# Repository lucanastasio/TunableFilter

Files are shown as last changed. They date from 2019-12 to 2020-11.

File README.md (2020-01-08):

# Tunable Filter with varactors
## Idea (our goal)
The idea of this project is the design of a tunable filter with variable resonance frequency. Achieving this would be possible using varactors. The varactors are used in place of the capacitors in resonators thanks to their abrupt juction that results in an high variation in capacitance with respect to the voltage applied across their terminals. So the varactor is the tuning component in this project. The use of this component will be explained in the following notes.

## Design specifications
The (approximate) design specifications used in the design of this filter are the following:

- ***Type of Filter:*** band-pass
- ***Type of Response:*** Chebyshev (equi-ripple)
- ***Order of the filter:*** Third Order
- ***Resonant frequency:***  (adjustable)
- ***Bandwitdh:***  (adjustable)
- ***Ports Impedances:*** 
- ***Ripple Level:***  (adjustable)

## Design of the ideal Filter
The project started with the design of the ideal pass-band filter in order to verify that all the specifications can be satisfied. For the design, the method used was ***Insertion Loss Method*** taking the low-pass Filter prototype and changing the series and shunt components in order to have a pass-band response. Below is the schematic of the ideal pass-band filter:

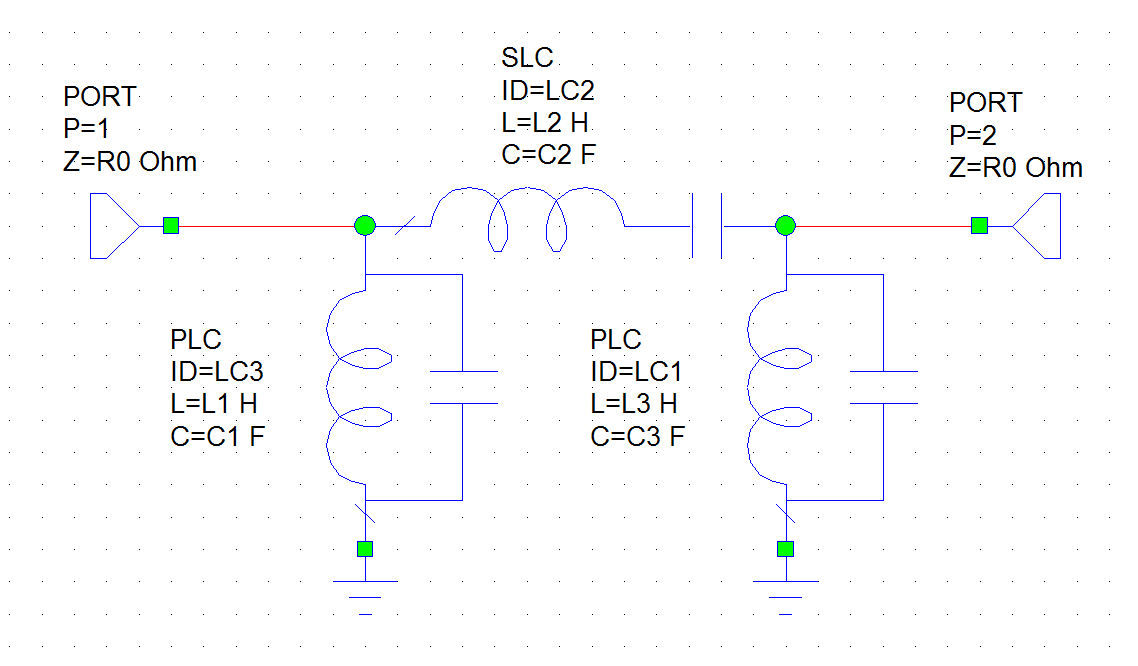
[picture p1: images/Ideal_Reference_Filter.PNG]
Ideal pass-band filter


Formulas used in the first design stage:

- 
- 
- 
- 
- 
- 

where:

-  : band-pass prototype filter coefficients, calculate as a third order Chebyshev filter [unitless]
-  : fractional bandwidth [%]
-  : angular frequency [rad/s]

The above formulas take into account impedance scaling and frequency scaling since the low-pass prototype uses an angular frequency at the resonant frequency of  and a source impedance of .
The resonant frequency (hence the fractional bandwidth) is not specified at this point of the design, instead it's left as a parameter. Then simulation environment's tuner tool (AWR) allows sweeping the parameter in its range.

In order to set an arbitrary inductor value for the resonators, impedance inverters were used with a proper value of ***K*** (inverter parameter). The resonator inductor value is called  in the schematic and its value is not yet determined, it's again a tunable value in order to obtain the best value which can be found as an off-the-shelf component. Thus, in the schematic of the pass-band filter, 4 impedance inverters were added, as shown in the following image:

Ideal pass-band filter with inverters

The resonator capacitor value is set by the equation:



The above equation gives the proper value of  for the desired resonat frequency.

Following are the formulas used to compute ***K*** parameters for each inverter:

- K for the impedence inverter at the source: 
- K for the second impedence inverter: 
- K for the third impedence inverter: 
- K for the impedence inverter at the load: 

where  is the source impedance,  is the bandwidth expressed in terms of angular frequency,  is the desired resonator inductance, and  are the band-pass filter prototype coefficients.

At this point impedance inverters are implemented as quarter-wave long transmission lines. The range of working frequencies spans from 0 to 1 GHz, so the physical length of the transmission lines results in an unfeasible dimension for a printed circuit board. To minimize board dimensions, the most reasonable choice is to implement the filter with lumped elements only, so an equivalent circuit for impedance inverters is required. For the 2 impedance inverters in the middle of the filter, the equivalent circuit is a T circuit composed of three capacitors where the shunt capacitor has a positive capacitance while the serires capacitors have a negative capacitance. Capacitors with negative capacitance are not physically possible but the use of this component is useful in the theoric design phase. Negative capacitors will be "absorbed" by the series with resonator capacitors, but only if the negative capacitors have a capacitance (in magnitude) greater than the resonator's one.
However, negative capacitances of impedance inverters at source and load ports are not "absorbed". To solve this problem another equivalent circuit is required for those two special cases, it consists of a shunt positive capacitor and only one series negative capacitor.
The schematic where all the impedance inverters are replaced with their respective equivalent circuits is shown in the figure:

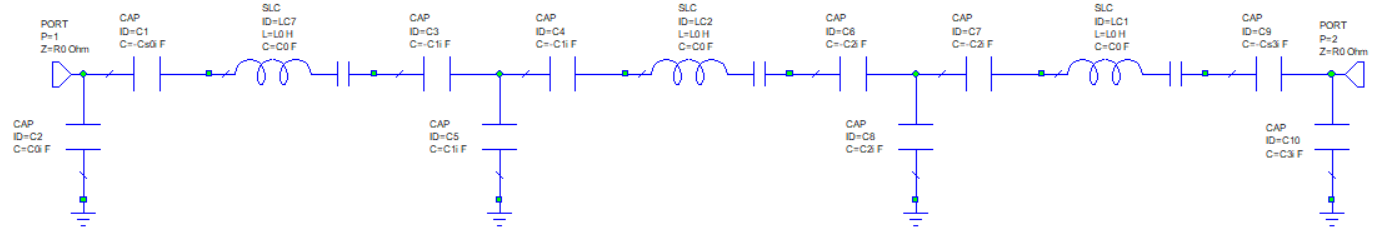
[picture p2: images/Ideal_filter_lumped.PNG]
Ideal pass-band filter with equivalent circuits of inverter Ideal pass-band filter with equivalent circuits of inverters


The formulas used to calculate capacitor values are:

- Impedance inverter at the source: 
	- shunt capacitor 
	- series capacitor 
- Second impedance inverter:
	- all capacitors have the same value 
- Third impedance inverter:
	- all capacitors have the same value 
- Impedance inverter at the load: 
	- shunt capacitor 
	- series capacitor 

Thanks to the symmetry of the circuit one has that  and .

As a last step of the design of the ideal pass-band filter, negative capacitors are "absorbed" by positive capacitors of the resonators. The final circuit is the following:

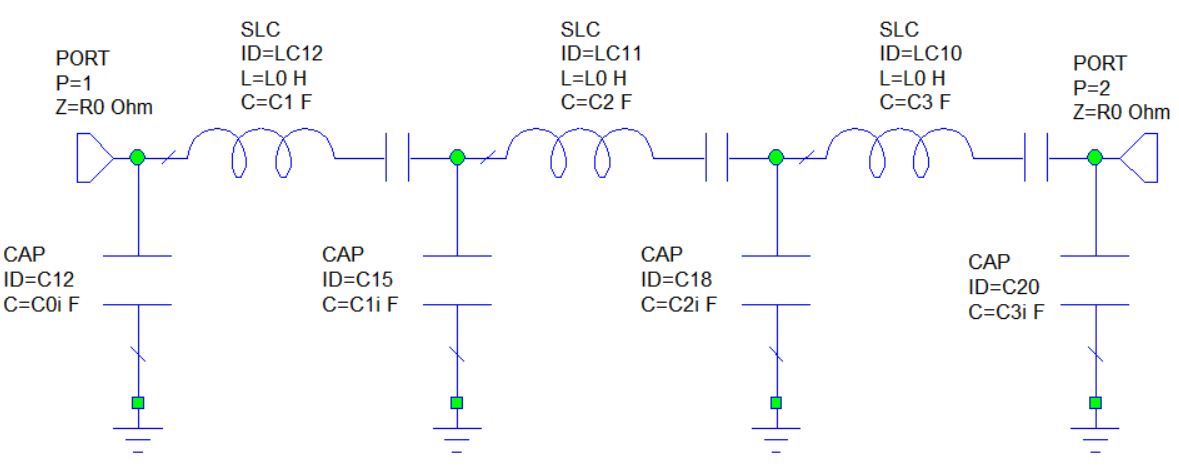
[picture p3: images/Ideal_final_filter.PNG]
Final design of the ideal pass-band filter


Capacitances are calculated using the well-known formula for series capacitance, thus:

- 
- 
- 

As per the circuit symmetry, .
It may be noted that the plus sign in front of  and  is due to the fact that the minus sign is inclued in their formulas.

Frequency response at the test resonant frequency of 1GHz of the final design of the ideal filter (without varactor) is shown below for ripple levels of 0.5 dB and 3dB respectively:

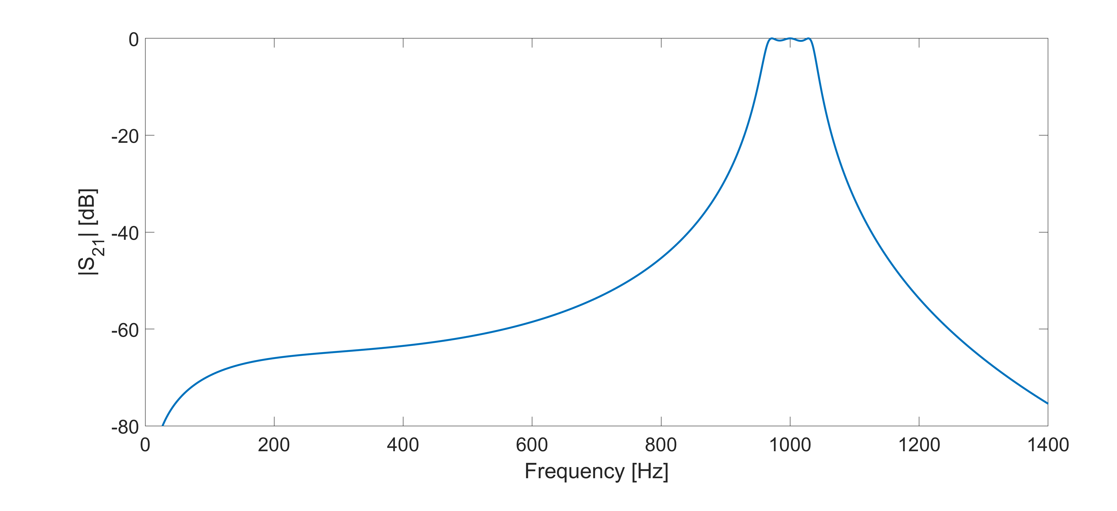
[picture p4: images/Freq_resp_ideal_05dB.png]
Frequency response 0.5dB Frequency response of the ideal filter for 0.5dB ripple level


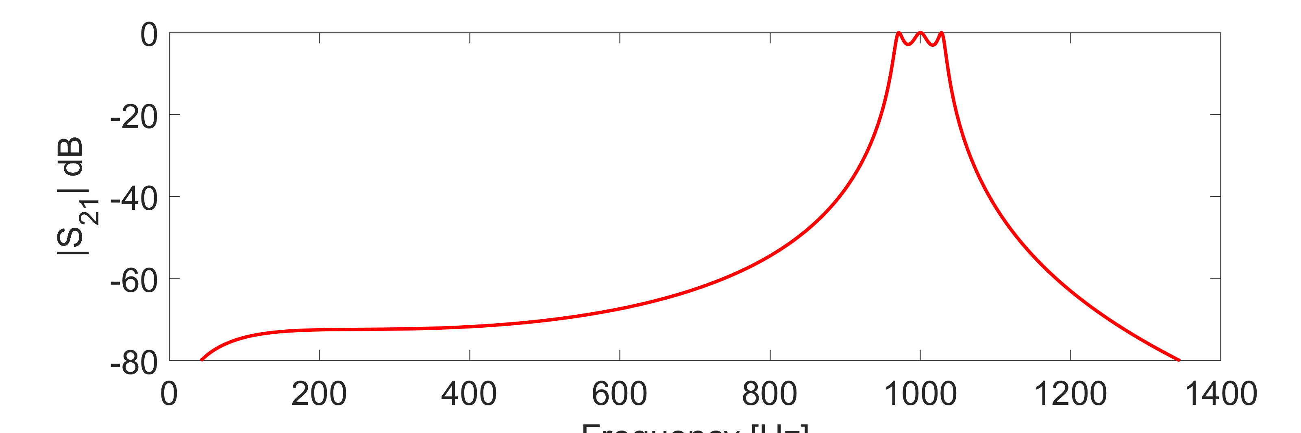
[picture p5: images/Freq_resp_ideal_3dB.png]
Frequency response 3dB Frequency response of the ideal filter for 3dB ripple level


## Adding tunable element: the varactor

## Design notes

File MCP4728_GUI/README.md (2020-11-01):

## Usage

### Driver
Only tested on Arch Linux, actual configuration may vary on your system, don't follow our isntructions blindly, do it at your own risk.

A CP2112 USB to i2c adapter has been used, but newer kernels don't load `i2c-dev` module on boot, load it on purpose with `sudo modprobe i2c-dev` and then, for your convenience, `echo '12c-dev' | sudo tee /etc/modules-load.d/i2c-dev.conf` to load it on boot.

Add an i2c group with `sudo groupadd i2c` to use it as normal user, add yourself to that group with `sudo usermod -a $USER -G i2c` and make the group effective in the current shell with `newgrp i2c` to avoid having to log out and back in.

Create an udev rule to ensure permission to use the adapter with `echo 'KERNEL=="i2c-[0-9]*", GROUP="i2c", MODE="0660"' | sudo tee /etc/udev/rules.d/99-i2c-dev.rules` and plug the adapter, finally.

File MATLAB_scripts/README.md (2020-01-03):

Extraction of the function that gives the biasing voltage to be applied to the diode in order to obtain the desired capacitance:

* Import the datasheet in Engauge Digitizer
* Extract the curve points and export the data
* Import the data in MATLAB and andjust the units if necessary
* Open the curve fitting tool and use C data for X axis and V data for Y axis
* Select the appropriate fitting type and adjust the fit
* To verify that the fit corresponds to the graph in the datasheet, first export the fit to the MATLAB workspace as "fit", then:
~~~matlab
plot(fit)
% comment/don't use the following if the voltage isn't in log scale
set(gca, 'YScale', 'log')
% swap X and Y axes
view([90 -90])
~~~

For example, the resulting function for BB202 extracted from the datasheet graph was:
~~~matlab
V(Cx) = (p1*Cx^3 + p2*Cx^2 + p3*Cx + p4) / (Cx^4 + q1*Cx^3 + q2*Cx^2 + q3*Cx + q4)
% with:
Cx = (C - 2.006e-11) / 9.593e-12
p1 = -1312
p2 = -4819
p3 = 2384
p4 = 1.172e+04
q1 = 974.2
q2 = 5311
q3 = 1.313e+04
q4 = 1.153e+04
~~~

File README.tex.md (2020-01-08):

# Tunable Filter with varactors
## Idea (our goal)
The idea of this project is the design of a tunable filter with variable resonance frequency. Achieving this would be possible using varactors. The varactors are used in place of the capacitors in resonators thanks to their abrupt juction that results in an high variation in capacitance with respect to the voltage applied across their terminals. So the varactor is the tuning component in this project. The use of this component will be explained in the following notes.

## Design specifications
The (approximate) design specifications used in the design of this filter are the following:

- ***Type of Filter:*** band-pass
- ***Type of Response:*** Chebyshev (equi-ripple)
- ***Order of the filter:*** Third Order
- ***Resonant frequency:*** $500MHz--1GHz$ (adjustable)
- ***Bandwitdh:*** $1\%-10\%$ (adjustable)
- ***Ports Impedances:*** $R_0=50\Omega$
- ***Ripple Level:*** $Ar=0.5\,dB$ (adjustable)

## Design of the ideal Filter
The project started with the design of the ideal pass-band filter in order to verify that all the specifications can be satisfied. For the design, the method used was ***Insertion Loss Method*** taking the low-pass Filter prototype and changing the series and shunt components in order to have a pass-band response. Below is the schematic of the ideal pass-band filter:

Ideal pass-band filter

Formulas used in the first design stage:

- $L1 = \frac{\Delta R_0}{g_1 \omega_0} H$
- $C1 = \frac{g_1}{\Delta R_0 \omega_0} F$
- $L2 = \frac{g_2 R_0}{\Delta \omega_0} H$
- $C2 = \frac{\Delta}{R_0 g_2 \omega_0} F$
- $L3 = \frac{\Delta R_0}{g_3 \omega_0} H$
- $C3 = \frac{g_3}{\Delta R_0 \omega_0} F$

where:

- $g_m$ : band-pass prototype filter coefficients, calculate as a third order Chebyshev filter [unitless]
- $\Delta$ : fractional bandwidth [%]
- $\omega_0$ : angular frequency [rad/s]

The above formulas take into account impedance scaling and frequency scaling since the low-pass prototype uses an angular frequency at the resonant frequency of $1 rad/sec$ and a source impedance of $R_0=1 \Omega$.
The resonant frequency (hence the fractional bandwidth) is not specified at this point of the design, instead it's left as a parameter. Then simulation environment's tuner tool (AWR) allows sweeping the parameter in its range.

In order to set an arbitrary inductor value for the resonators, impedance inverters were used with a proper value of ***K*** (inverter parameter). The resonator inductor value is called $L_0$ in the schematic and its value is not yet determined, it's again a tunable value in order to obtain the best value which can be found as an off-the-shelf component. Thus, in the schematic of the pass-band filter, 4 impedance inverters were added, as shown in the following image:

Ideal pass-band filter with inverters

The resonator capacitor value is set by the equation:

\begin{equation}
C_0 = \frac{1}{L_0 \omega_0^2}
\end{equation}

The above equation gives the proper value of $C_0$ for the desired resonat frequency.

Following are the formulas used to compute ***K*** parameters for each inverter:

- K for the impedence inverter at the source: $K_0=\sqrt{\frac{R_0 L_0BW}{g_0 g_1}}$
- K for the second impedence inverter: $K_1=\frac{BW L_0}{g_1 g_2}$
- K for the third impedence inverter: $K_2=\frac{BW L_0}{g_2 g_3}$
- K for the impedence inverter at the load: $K_3=\sqrt{\frac{R_0 L_0 BW}{g_3 g_4}}$

where $R_0$ is the source impedance, $BW$ is the bandwidth expressed in terms of angular frequency, $L_0$ is the desired resonator inductance, and $g_i$ are the band-pass filter prototype coefficients.

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

Ideal pass-band filter with equivalent circuits of inverter Ideal pass-band filter with equivalent circuits of inverters

The formulas used to calculate capacitor values are:

- Impedance inverter at the source: 
	- shunt capacitor $C_{0i} = \frac{\sqrt{1-\left(\frac{K_0}{R_0}\right)^2}}{K_0 \omega_0}$
	- series capacitor $C_{s0i}=-C_{0i}-\frac{1}{\left(R_0 \omega_0\right)^2 C_{0i}}$
- Second impedance inverter:
	- all capacitors have the same value $C_{1i} =\frac{1}{\omega_0 K_1}$
- Third impedance inverter:
	- all capacitors have the same value $C_{2i} =\frac{1}{\omega_0 K_2}$
- Impedance inverter at the load: 
	- shunt capacitor $C_{3i} = \frac{\sqrt{1-\left(\frac{K_3}{R_0}\right)^2}}{K_3 \omega_0}$
	- series capacitor $C_{s3i}=-C_{3i}-\frac{1}{\left(R_0 \omega_0\right)^2 C_{3i}}$

Thanks to the symmetry of the circuit one has that $C_{s3i}=C_{s0i}$ and $C0i=C_{3i}$.

As a last step of the design of the ideal pass-band filter, negative capacitors are "absorbed" by positive capacitors of the resonators. The final circuit is the following:

Final design of the ideal pass-band filter

Capacitances are calculated using the well-known formula for series capacitance, thus:

- $C_1=\frac{1}{\frac{1}{C_0}+\frac{1}{C_{s0i}}-\frac{1}{C_{1i}}}$
- $C_2=\frac{1}{\frac{1}{C_0}-\frac{1}{C_{1i}}-\frac{1}{C_{2i}}}$
- $C_3=\frac{1}{\frac{1}{C_0}+\frac{1}{C_{s3i}}-\frac{1}{C_{2i}}}$

As per the circuit symmetry, $C_1=C_3$.
It may be noted that the plus sign in front of $C_{s0i}$ and $C_{s3i}$ is due to the fact that the minus sign is inclued in their formulas.

Frequency response at the test resonant frequency of 1GHz of the final design of the ideal filter (without varactor) is shown below for ripple levels of 0.5 dB and 3dB respectively:

Frequency response 0.5dB Frequency response of the ideal filter for 0.5dB ripple level

Frequency response 3dB Frequency response of the ideal filter for 3dB ripple level

## Adding tunable element: the varactor

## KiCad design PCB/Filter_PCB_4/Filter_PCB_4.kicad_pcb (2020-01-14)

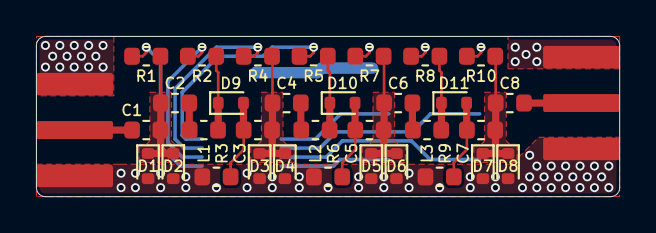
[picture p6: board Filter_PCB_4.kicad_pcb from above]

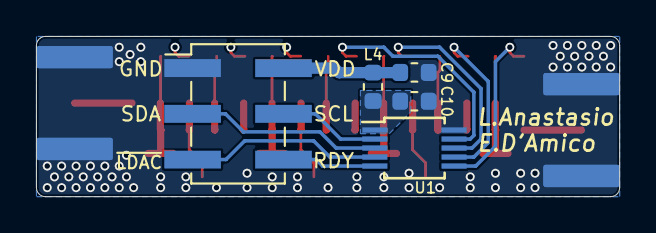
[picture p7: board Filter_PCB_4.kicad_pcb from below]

Board: 4 copper layers, 32.4 x 8.9 mm, 39 parts (5 on the bottom side), 26 nets.

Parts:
C1, C2, C3, C4, C5, C6, C7, C8, C10: 100n; C_0603_1608Metric
C9: 4.7u; C_0603_1608Metric
D1, D2, D3, D4, D5, D6, D7, D8, D9, D10, D11: BB202; D_SOD-523
J1, J2: Conn_Coaxial; SMA_generic_EdgeMount
J3: Conn_01x06_Male; PinHeader_2x03_P2.54mm_Vertical_SMD
L1, L2, L3: L0; Coilcraft_0603CS
L4: 180R; L_0603_1608Metric
R1, R2, R3, R4, R5, R6, R7, R8, R9, R10: 100k; R_0603_1608Metric
U1: MCP4728; MSOP-10_3x3mm_P0.5mm

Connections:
/DAC/RDY: J3.6, U1.5
/DAC/SCL: J3.4, U1.2
/DAC/SDA: J3.3, U1.3
/DAC/~LDAC: J3.5, U1.4
/RF/RFin: C1.1, J1.1
/RF/RFout: C8.2, J2.1
/RF/V0: R1.1, R10.1, U1.6
/RF/V1: R2.1, R8.1, U1.7
/RF/V2: R4.1, R7.1, U1.8
/RF/V3: R5.1, U1.9
/RF/inv0/Vd: C1.2, C2.1, D1.1, D2.1, R1.2
/RF/inv1/In: C3.1, D9.2, R3.1
/RF/inv1/Vd: C3.2, C4.1, D3.1, D4.1, R4.2
/RF/inv2/In: C5.1, D10.2, R6.1
/RF/inv2/Vd: C5.2, C6.1, D5.1, D6.1, R7.2
/RF/inv3/In: C7.1, D11.2, R9.1
/RF/inv3/Vd: C7.2, C8.1, D7.1, D8.1, R10.2
/RF/res0/In: C2.2, L1.1
/RF/res0/Vd+: D9.1, L1.2, R2.2
/RF/res1/In: C4.2, L2.1
/RF/res1/Vd+: D10.1, L2.2, R5.2
/RF/res2/In: C6.2, L3.1
/RF/res2/Vd+: D11.1, L3.2, R8.2
GND: C9.2, C10.2, D1.2, D2.2, D3.2, D4.2, D5.2, D6.2, D7.2, D8.2, J1.2, J2.2, J3.1, R3.2, R6.2, R9.2, U1.10
VDD: C9.1, J3.2, L4.2
VDDA: C10.1, L4.1, U1.1

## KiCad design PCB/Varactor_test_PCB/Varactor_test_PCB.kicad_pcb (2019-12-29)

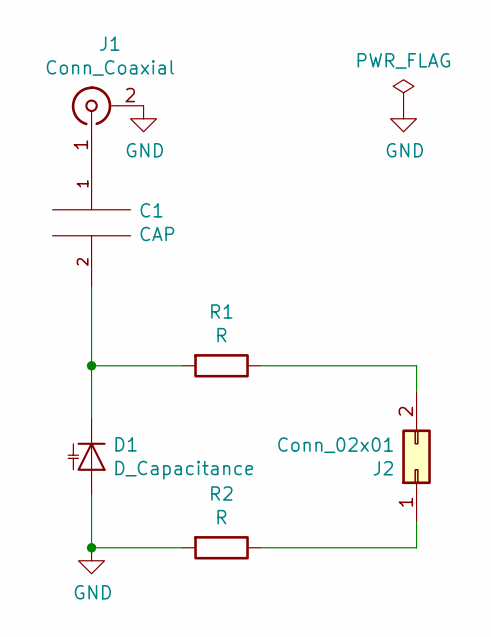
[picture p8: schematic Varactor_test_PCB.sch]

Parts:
C1: CAP; C_0603_1608Metric
D1: D_Capacitance; D_SOD-523
J1: Conn_Coaxial; SMA_generic_EdgeMount
J2: Conn_02x01; PinHeader_2x01_P2.54mm_Vertical
R1, R2: R; R_0603_1608Metric

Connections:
GND: D1.2 (A), J1.2 (Ext), R2.2
unnamed: C1.1, J1.1 (In)
unnamed: C1.2, D1.1 (K), R1.2
unnamed: J2.1, R2.1
unnamed: J2.2, R1.1

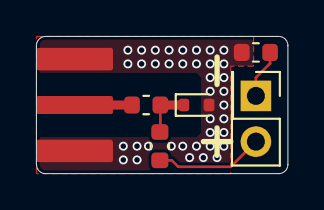
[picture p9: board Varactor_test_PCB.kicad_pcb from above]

Board: 2 copper layers, 14.0 x 7.6 mm, 6 parts (0 on the bottom side), 5 nets.

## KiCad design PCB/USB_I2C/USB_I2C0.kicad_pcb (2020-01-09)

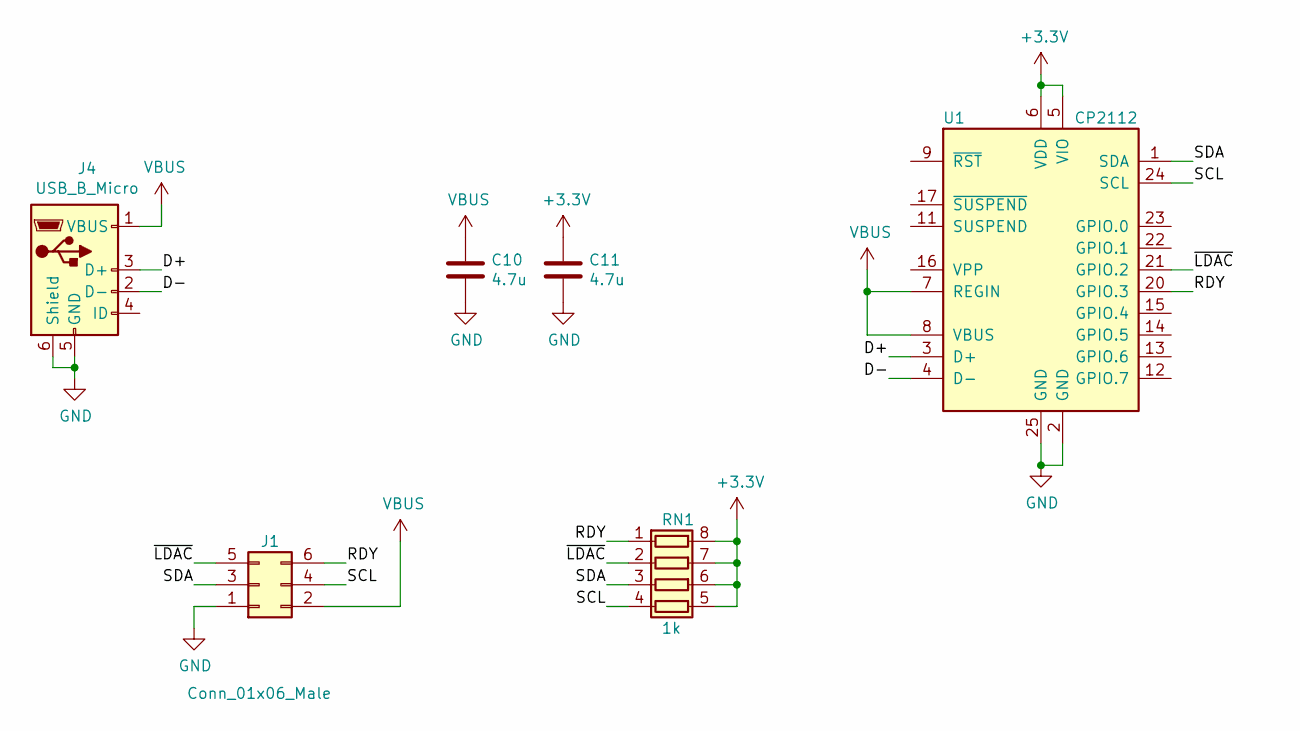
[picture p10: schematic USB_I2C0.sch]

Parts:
C10, C11: 4.7u; C_0603_1608Metric
J1: Conn_01x06_Male; PinHeader_2x03_P2.54mm_Vertical_SMD
J4: USB_B_Micro; USB_Micro-B_Molex_47346-0001
RN1: 1k; R_Array_Convex_4x0603
U1: CP2112; QFN-24-1EP_4x4mm_P0.5mm_EP2.6x2.6mm

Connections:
+3V3: C11.1, RN1.5 (R4.2), RN1.6 (R3.2), RN1.7 (R2.2), RN1.8 (R1.2), U1.5 (VIO), U1.6 (VDD)
/D+: J4.3 (D+), U1.3 (D+)
/D-: J4.2 (D-), U1.4 (D-)
/RDY: J1.6, RN1.1 (R1.1), U1.20 (GPIO.3)
/SCL: J1.4, RN1.4 (R4.1), U1.24 (SCL)
/SDA: J1.3, RN1.3 (R3.1), U1.1 (SDA)
/~LDAC: J1.5, RN1.2 (R2.1), U1.21 (GPIO.2)
GND: C10.2, C11.2, J1.1, J4.5 (GND), J4.6 (Shield), U1.2 (GND), U1.25 (GND)
VBUS: C10.1, J1.2, J4.1 (VBUS), U1.7 (REGIN), U1.8 (VBUS)

Board: 2 copper layers, 6 parts (0 on the bottom side), 9 nets, no tracks yet.

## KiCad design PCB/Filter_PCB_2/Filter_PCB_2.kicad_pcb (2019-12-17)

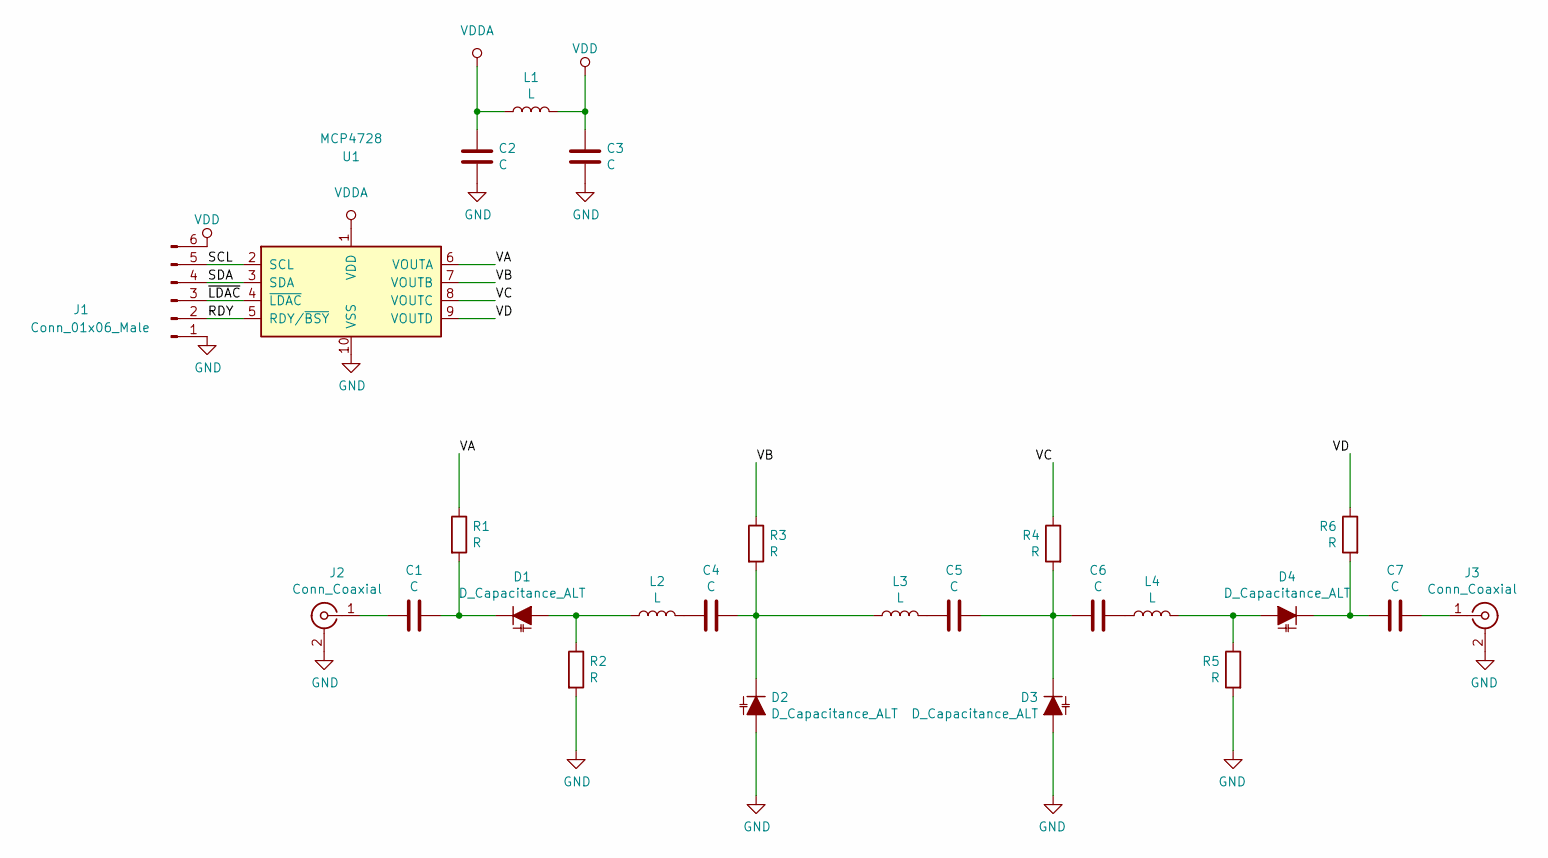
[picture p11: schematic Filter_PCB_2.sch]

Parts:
C1, C2, C3, C4, C5, C6, C7: C; C_0603_1608Metric
D1, D2, D3, D4: D_Capacitance_ALT; D_SOD-523
J1: Conn_01x06_Male; SMD_1x06_P2.54mm_Horizontal
J2, J3: Conn_Coaxial; SMA_generic_EdgeMount
L1, L2, L3, L4: L; L_0603_1608Metric
R1, R2, R3, R4, R5, R6: R; R_0603_1608Metric
U1: MCP4728; MSOP-10_3x3mm_P0.5mm

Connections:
/RDY: J1.2, U1.5 (RDY/~BSY)
/SCL: J1.5, U1.2 (SCL)
/SDA: J1.4, U1.3 (SDA)
/VA: R1.1, U1.6 (VOUTA)
/VB: R3.1, U1.7 (VOUTB)
/VC: R4.1, U1.8 (VOUTC)
/VD: R6.1, U1.9 (VOUTD)
/~LDAC: J1.3, U1.4 (~LDAC)
GND: C2.2, C3.2, D2.2 (A), D3.2 (A), J1.1, J2.2 (Ext), J3.2 (Ext), R2.2, R5.2, U1.10 (VSS)
unnamed: C1.1, J2.1 (In)
unnamed: C1.2, D1.1 (K), R1.2
unnamed: C4.1, D2.1 (K), L3.1, R3.2
unnamed: C4.2, L2.2
unnamed: C5.1, C6.1, D3.1 (K), R4.2
unnamed: C5.2, L3.2
unnamed: C6.2, L4.2
unnamed: C7.1, J3.1 (In)
unnamed: C7.2, D4.1 (K), R6.2
unnamed: D1.2 (A), L2.1, R2.1
unnamed: D4.2 (A), L4.1, R5.1
VDD: C3.1, J1.6, L1.2
VDDA: C2.1, L1.1, U1.1 (VDD)

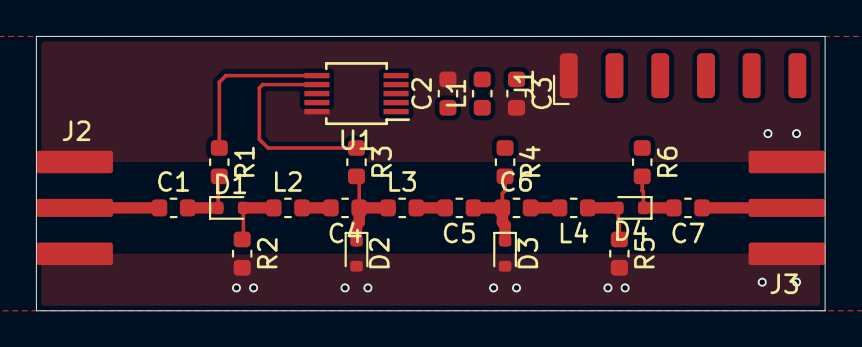
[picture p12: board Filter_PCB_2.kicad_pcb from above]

Board: 2 copper layers, 43.8 x 15.2 mm, 25 parts (0 on the bottom side), 22 nets.

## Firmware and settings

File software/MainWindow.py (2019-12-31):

# -*- coding: utf-8 -*-

# Form implementation generated from reading ui file 'MainWindow.ui'
#
# Created by: PyQt5 UI code generator 5.11.2
#
# WARNING! All changes made in this file will be lost!

from PyQt5 import QtCore, QtGui, QtWidgets

class Ui_MainWindow(object):
    def setupUi(self, MainWindow):
        MainWindow.setObjectName("MainWindow")
        MainWindow.resize(902, 520)
        sizePolicy = QtWidgets.QSizePolicy(QtWidgets.QSizePolicy.Fixed, QtWidgets.QSizePolicy.MinimumExpanding)
        sizePolicy.setHorizontalStretch(0)
        sizePolicy.setVerticalStretch(0)
        sizePolicy.setHeightForWidth(MainWindow.sizePolicy().hasHeightForWidth())
        MainWindow.setSizePolicy(sizePolicy)
        MainWindow.setMinimumSize(QtCore.QSize(902, 520))
        MainWindow.setMaximumSize(QtCore.QSize(902, 1000))
        MainWindow.setInputMethodHints(QtCore.Qt.ImhNone)
        self.centralwidget = QtWidgets.QWidget(MainWindow)
        sizePolicy = QtWidgets.QSizePolicy(QtWidgets.QSizePolicy.Maximum, QtWidgets.QSizePolicy.MinimumExpanding)
        sizePolicy.setHorizontalStretch(0)
        sizePolicy.setVerticalStretch(0)
        sizePolicy.setHeightForWidth(self.centralwidget.sizePolicy().hasHeightForWidth())
        self.centralwidget.setSizePolicy(sizePolicy)
        self.centralwidget.setLayoutDirection(QtCore.Qt.LeftToRight)
        self.centralwidget.setObjectName("centralwidget")
        self.horizontalLayout_10 = QtWidgets.QHBoxLayout(self.centralwidget)
        self.horizontalLayout_10.setObjectName("horizontalLayout_10")
        self.verticalLayout_5 = QtWidgets.QVBoxLayout()
        self.verticalLayout_5.setSizeConstraint(QtWidgets.QLayout.SetDefaultConstraint)
        self.verticalLayout_5.setContentsMargins(10, 10, 10, 0)
        self.verticalLayout_5.setObjectName("verticalLayout_5")
        self.horizontalLayout = QtWidgets.QHBoxLayout()
        self.horizontalLayout.setObjectName("horizontalLayout")
        self.groupBox = QtWidgets.QGroupBox(self.centralwidget)
        self.groupBox.setStyleSheet("border-color: black")
        self.groupBox.setObjectName("groupBox")
        self.verticalLayout_3 = QtWidgets.QVBoxLayout(self.groupBox)
        self.verticalLayout_3.setObjectName("verticalLayout_3")
        self.SliderA = QtWidgets.QSlider(self.groupBox)
        sizePolicy = QtWidgets.QSizePolicy(QtWidgets.QSizePolicy.Fixed, QtWidgets.QSizePolicy.MinimumExpanding)
        sizePolicy.setHorizontalStretch(0)
        sizePolicy.setVerticalStretch(0)
        sizePolicy.setHeightForWidth(self.SliderA.sizePolicy().hasHeightForWidth())
        self.SliderA.setSizePolicy(sizePolicy)
        self.SliderA.setMinimumSize(QtCore.QSize(0, 256))
        self.SliderA.setInputMethodHints(QtCore.Qt.ImhNone)
        self.SliderA.setMaximum(4095)
        self.SliderA.setPageStep(12)
        self.SliderA.setProperty("value", 0)
        self.SliderA.setSliderPosition(0)
        self.SliderA.setTracking(True)
        self.SliderA.setOrientation(QtCore.Qt.Vertical)
        self.SliderA.setTickPosition(QtWidgets.QSlider.TicksBothSides)
        self.SliderA.setTickInterval(256)
        self.SliderA.setObjectName("SliderA")
        self.verticalLayout_3.addWidget(self.SliderA, 0, QtCore.Qt.AlignHCenter)
        self.SpinBoxA = QtWidgets.QDoubleSpinBox(self.groupBox)
        sizePolicy = QtWidgets.QSizePolicy(QtWidgets.QSizePolicy.Fixed, QtWidgets.QSizePolicy.Fixed)
        sizePolicy.setHorizontalStretch(0)
        sizePolicy.setVerticalStretch(0)
        sizePolicy.setHeightForWidth(self.SpinBoxA.sizePolicy().hasHeightForWidth())
        self.SpinBoxA.setSizePolicy(sizePolicy)
        self.SpinBoxA.setMinimumSize(QtCore.QSize(110, 0))
        self.SpinBoxA.setPrefix("")
        self.SpinBoxA.setDecimals(4)
        self.SpinBoxA.setMaximum(2.0475)
        self.SpinBoxA.setSingleStep(0.0005)
        self.SpinBoxA.setObjectName("SpinBoxA")
        self.verticalLayout_3.addWidget(self.SpinBoxA, 0, QtCore.Qt.AlignHCenter)
        self.horizontalLayout_2 = QtWidgets.QHBoxLayout()
        self.horizontalLayout_2.setSpacing(10)
        self.horizontalLayout_2.setObjectName("horizontalLayout_2")
        self.label = QtWidgets.QLabel(self.groupBox)
        sizePolicy = QtWidgets.QSizePolicy(QtWidgets.QSizePolicy.Maximum, QtWidgets.QSizePolicy.Preferred)
        sizePolicy.setHorizontalStretch(0)
        sizePolicy.setVerticalStretch(0)
        sizePolicy.setHeightForWidth(self.label.sizePolicy().hasHeightForWidth())
        self.label.setSizePolicy(sizePolicy)
        self.label.setObjectName("label")
        self.horizontalLayout_2.addWidget(self.label, 0, QtCore.Qt.AlignRight)
        self.VrefA = QtWidgets.QComboBox(self.groupBox)
        sizePolicy = QtWidgets.QSizePolicy(QtWidgets.QSizePolicy.Fixed, QtWidgets.QSizePolicy.Preferred)
        sizePolicy.setHorizontalStretch(0)
        sizePolicy.setVerticalStretch(0)
        sizePolicy.setHeightForWidth(self.VrefA.sizePolicy().hasHeightForWidth())
        self.VrefA.setSizePolicy(sizePolicy)
        self.VrefA.setMinimumSize(QtCore.QSize(140, 0))
        self.VrefA.setObjectName("VrefA")
        self.VrefA.addItem("")
        self.VrefA.addItem("")
        self.VrefA.addItem("")
        self.horizontalLayout_2.addWidget(self.VrefA)
        self.verticalLayout_3.addLayout(self.horizontalLayout_2)
        self.horizontalLayout.addWidget(self.groupBox, 0, QtCore.Qt.AlignHCenter)
        self.groupBox1 = QtWidgets.QGroupBox(self.centralwidget)
        self.groupBox1.setStyleSheet("border-color: black")
        self.groupBox1.setObjectName("groupBox1")
        self.verticalLayout_4 = QtWidgets.QVBoxLayout(self.groupBox1)
        self.verticalLayout_4.setObjectName("verticalLayout_4")
        self.SliderB = QtWidgets.QSlider(self.groupBox1)
        sizePolicy = QtWidgets.QSizePolicy(QtWidgets.QSizePolicy.Fixed, QtWidgets.QSizePolicy.MinimumExpanding)
        sizePolicy.setHorizontalStretch(0)
        sizePolicy.setVerticalStretch(0)
        sizePolicy.setHeightForWidth(self.SliderB.sizePolicy().hasHeightForWidth())
        self.SliderB.setSizePolicy(sizePolicy)
        self.SliderB.setMinimumSize(QtCore.QSize(0, 256))
        self.SliderB.setInputMethodHints(QtCore.Qt.ImhNone)
        self.SliderB.setMaximum(4095)
        self.SliderB.setPageStep(12)
        self.SliderB.setProperty("value", 0)
        self.SliderB.setSliderPosition(0)
        self.SliderB.setTracking(True)
        self.SliderB.setOrientation(QtCore.Qt.Vertical)
        self.SliderB.setTickPosition(QtWidgets.QSlider.TicksBothSides)
        self.SliderB.setTickInterval(256)
        self.SliderB.setObjectName("SliderB")
        self.verticalLayout_4.addWidget(self.SliderB, 0, QtCore.Qt.AlignHCenter)
        self.SpinBoxB = QtWidgets.QDoubleSpinBox(self.groupBox1)
        sizePolicy = QtWidgets.QSizePolicy(QtWidgets.QSizePolicy.Fixed, QtWidgets.QSizePolicy.Fixed)
        sizePolicy.setHorizontalStretch(0)
        sizePolicy.setVerticalStretch(0)
        sizePolicy.setHeightForWidth(self.SpinBoxB.sizePolicy().hasHeightForWidth())
        self.SpinBoxB.setSizePolicy(sizePolicy)
        self.SpinBoxB.setMinimumSize(QtCore.QSize(110, 0))
        self.SpinBoxB.setPrefix("")
        self.SpinBoxB.setDecimals(4)
        self.SpinBoxB.setMaximum(2.0475)
        self.SpinBoxB.setSingleStep(0.0005)
        self.SpinBoxB.setObjectName("SpinBoxB")
        self.verticalLayout_4.addWidget(self.SpinBoxB, 0, QtCore.Qt.AlignHCenter)
        self.horizontalLayout_3 = QtWidgets.QHBoxLayout()
        self.horizontalLayout_3.setSpacing(10)
        self.horizontalLayout_3.setObjectName("horizontalLayout_3")
        self.label_2 = QtWidgets.QLabel(self.groupBox1)
        sizePolicy = QtWidgets.QSizePolicy(QtWidgets.QSizePolicy.Maximum, QtWidgets.QSizePolicy.Preferred)
        sizePolicy.setHorizontalStretch(0)
        sizePolicy.setVerticalStretch(0)
        sizePolicy.setHeightForWidth(self.label_2.sizePolicy().hasHeightForWidth())
        self.label_2.setSizePolicy(sizePolicy)
        self.label_2.setObjectName("label_2")
        self.horizontalLayout_3.addWidget(self.label_2, 0, QtCore.Qt.AlignRight)
        self.VrefB = QtWidgets.QComboBox(self.groupBox1)
        sizePolicy = QtWidgets.QSizePolicy(QtWidgets.QSizePolicy.Fixed, QtWidgets.QSizePolicy.Fixed)
        sizePolicy.setHorizontalStretch(0)
        sizePolicy.setVerticalStretch(0)
        sizePolicy.setHeightForWidth(self.VrefB.sizePolicy().hasHeightForWidth())
        self.VrefB.setSizePolicy(sizePolicy)
        self.VrefB.setMinimumSize(QtCore.QSize(140, 0))
        self.VrefB.setObjectName("VrefB")
        self.VrefB.addItem("")
        self.VrefB.addItem("")
        self.VrefB.addItem("")
        self.horizontalLayout_3.addWidget(self.VrefB)
        self.verticalLayout_4.addLayout(self.horizontalLayout_3)
        self.horizontalLayout.addWidget(self.groupBox1, 0, QtCore.Qt.AlignHCenter)
        self.groupBox2 = QtWidgets.QGroupBox(self.centralwidget)
        self.groupBox2.setStyleSheet("border-color: black")
        self.groupBox2.setObjectName("groupBox2")
        self.verticalLayout = QtWidgets.QVBoxLayout(self.groupBox2)
        self.verticalLayout.setObjectName("verticalLayout")
        self.SliderC = QtWidgets.QSlider(self.groupBox2)
        sizePolicy = QtWidgets.QSizePolicy(QtWidgets.QSizePolicy.Fixed, QtWidgets.QSizePolicy.MinimumExpanding)
        sizePolicy.setHorizontalStretch(0)
        sizePolicy.setVerticalStretch(0)
        sizePolicy.setHeightForWidth(self.SliderC.sizePolicy().hasHeightForWidth())
        self.SliderC.setSizePolicy(sizePolicy)
        self.SliderC.setMinimumSize(QtCore.QSize(0, 256))
        self.SliderC.setInputMethodHints(QtCore.Qt.ImhNone)
        self.SliderC.setMaximum(4095)
        self.SliderC.setPageStep(12)
        self.SliderC.setProperty("value", 0)
        self.SliderC.setSliderPosition(0)
        self.SliderC.setTracking(True)
        self.SliderC.setOrientation(QtCore.Qt.Vertical)
        self.SliderC.setTickPosition(QtWidgets.QSlider.TicksBothSides)
        self.SliderC.setTickInterval(256)
        self.SliderC.setObjectName("SliderC")
        self.verticalLayout.addWidget(self.SliderC, 0, QtCore.Qt.AlignHCenter)
        self.SpinBoxC = QtWidgets.QDoubleSpinBox(self.groupBox2)
        sizePolicy = QtWidgets.QSizePolicy(QtWidgets.QSizePolicy.Fixed, QtWidgets.QSizePolicy.Fixed)
        sizePolicy.setHorizontalStretch(0)
        sizePolicy.setVerticalStretch(0)
        sizePolicy.setHeightForWidth(self.SpinBoxC.sizePolicy().hasHeightForWidth())
        self.SpinBoxC.setSizePolicy(sizePolicy)
        self.SpinBoxC.setMinimumSize(QtCore.QSize(110, 0))
        self.SpinBoxC.setPrefix("")
        self.SpinBoxC.setDecimals(4)
        self.SpinBoxC.setMaximum(2.0475)
        self.SpinBoxC.setSingleStep(0.0005)
        self.SpinBoxC.setObjectName("SpinBoxC")
        self.verticalLayout.addWidget(self.SpinBoxC, 0, QtCore.Qt.AlignHCenter)
        self.horizontalLayout_4 = QtWidgets.QHBoxLayout()
        self.horizontalLayout_4.setSpacing(10)
        self.horizontalLayout_4.setObjectName("horizontalLayout_4")
        self.label_3 = QtWidgets.QLabel(self.groupBox2)
        sizePolicy = QtWidgets.QSizePolicy(QtWidgets.QSizePolicy.Maximum, QtWidgets.QSizePolicy.Preferred)
        sizePolicy.setHorizontalStretch(0)
        sizePolicy.setVerticalStretch(0)
        sizePolicy.setHeightForWidth(self.label_3.sizePolicy().hasHeightForWidth())
        self.label_3.setSizePolicy(sizePolicy)
        self.label_3.setObjectName("label_3")
        self.horizontalLayout_4.addWidget(self.label_3, 0, QtCore.Qt.AlignRight)
        self.VrefC = QtWidgets.QComboBox(self.groupBox2)
        sizePolicy = QtWidgets.QSizePolicy(QtWidgets.QSizePolicy.Fixed, QtWidgets.QSizePolicy.Fixed)
        sizePolicy.setHorizontalStretch(0)
        sizePolicy.setVerticalStretch(0)
        sizePolicy.setHeightForWidth(self.VrefC.sizePolicy().hasHeightForWidth())
        self.VrefC.setSizePolicy(sizePolicy)
        self.VrefC.setMinimumSize(QtCore.QSize(140, 0))
        self.VrefC.setObjectName("VrefC")
        self.VrefC.addItem("")
        self.VrefC.addItem("")
        self.VrefC.addItem("")
        self.horizontalLayout_4.addWidget(self.VrefC)
        self.verticalLayout.addLayout(self.horizontalLayout_4)
        self.horizontalLayout.addWidget(self.groupBox2, 0, QtCore.Qt.AlignHCenter)
        self.groupBox3 = QtWidgets.QGroupBox(self.centralwidget)
        self.groupBox3.setStyleSheet("border-color: black")
        self.groupBox3.setAlignment(QtCore.Qt.AlignCenter)
        self.groupBox3.setObjectName("groupBox3")
        self.verticalLayout_2 = QtWidgets.QVBoxLayout(self.groupBox3)
        self.verticalLayout_2.setObjectName("verticalLayout_2")
        self.SliderD = QtWidgets.QSlider(self.groupBox3)
        sizePolicy = QtWidgets.QSizePolicy(QtWidgets.QSizePolicy.Fixed, QtWidgets.QSizePolicy.MinimumExpanding)
        sizePolicy.setHorizontalStretch(0)
        sizePolicy.setVerticalStretch(0)
        sizePolicy.setHeightForWidth(self.SliderD.sizePolicy().hasHeightForWidth())
        self.SliderD.setSizePolicy(sizePolicy)
        self.SliderD.setMinimumSize(QtCore.QSize(0, 256))
        self.SliderD.setInputMethodHints(QtCore.Qt.ImhNone)
        self.SliderD.setMaximum(4095)
        self.SliderD.setPageStep(12)
        self.SliderD.setProperty("value", 0)
        self.SliderD.setSliderPosition(0)
        self.SliderD.setTracking(True)
        self.SliderD.setOrientation(QtCore.Qt.Vertical)
        self.SliderD.setTickPosition(QtWidgets.QSlider.TicksBothSides)
        self.SliderD.setTickInterval(256)
        self.SliderD.setObjectName("SliderD")
        self.verticalLayout_2.addWidget(self.SliderD, 0, QtCore.Qt.AlignHCenter)
        self.SpinBoxD = QtWidgets.QDoubleSpinBox(self.groupBox3)
        sizePolicy = QtWidgets.QSizePolicy(QtWidgets.QSizePolicy.Fixed, QtWidgets.QSizePolicy.Fixed)
        sizePolicy.setHorizontalStretch(0)
        sizePolicy.setVerticalStretch(0)
        sizePolicy.setHeightForWidth(self.SpinBoxD.sizePolicy().hasHeightForWidth())
        self.SpinBoxD.setSizePolicy(sizePolicy)
        self.SpinBoxD.setMinimumSize(QtCore.QSize(110, 0))
        self.SpinBoxD.setPrefix("")
        self.SpinBoxD.setDecimals(4)
        self.SpinBoxD.setMaximum(2.0475)
        self.SpinBoxD.setSingleStep(0.0005)
        self.SpinBoxD.setObjectName("SpinBoxD")
        self.verticalLayout_2.addWidget(self.SpinBoxD, 0, QtCore.Qt.AlignHCenter)
        self.horizontalLayout_5 = QtWidgets.QHBoxLayout()
        self.horizontalLayout_5.setSpacing(10)
        self.horizontalLayout_5.setObjectName("horizontalLayout_5")
        self.label_4 = QtWidgets.QLabel(self.groupBox3)
        sizePolicy = QtWidgets.QSizePolicy(QtWidgets.QSizePolicy.Maximum, QtWidgets.QSizePolicy.Preferred)
        sizePolicy.setHorizontalStretch(0)
        sizePolicy.setVerticalStretch(0)
        sizePolicy.setHeightForWidth(self.label_4.sizePolicy().hasHeightForWidth())
        self.label_4.setSizePolicy(sizePolicy)
        self.label_4.setObjectName("label_4")
        self.horizontalLayout_5.addWidget(self.label_4, 0, QtCore.Qt.AlignRight)
        self.VrefD = QtWidgets.QComboBox(self.groupBox3)
        sizePolicy = QtWidgets.QSizePolicy(QtWidgets.QSizePolicy.Fixed, QtWidgets.QSizePolicy.Fixed)
        sizePolicy.setHorizontalStretch(0)
        sizePolicy.setVerticalStretch(0)
        sizePolicy.setHeightForWidth(self.VrefD.sizePolicy().hasHeightForWidth())
        self.VrefD.setSizePolicy(sizePolicy)
        self.VrefD.setMinimumSize(QtCore.QSize(140, 0))
        self.VrefD.setObjectName("VrefD")
        self.VrefD.addItem("")
        self.VrefD.addItem("")
        self.VrefD.addItem("")
        self.horizontalLayout_5.addWidget(self.VrefD)
        self.verticalLayout_2.addLayout(self.horizontalLayout_5)
        self.horizontalLayout.addWidget(self.groupBox3, 0, QtCore.Qt.AlignHCenter)
        self.verticalLayout_5.addLayout(self.horizontalLayout)
        spacerItem = QtWidgets.QSpacerItem(20, 10, QtWidgets.QSizePolicy.Minimum, QtWidgets.QSizePolicy.Fixed)
        self.verticalLayout_5.addItem(spacerItem)
        self.gridLayout = QtWidgets.QGridLayout()
        self.gridLayout.setHorizontalSpacing(10)
        self.gridLayout.setVerticalSpacing(6)
        self.gridLayout.setObjectName("gridLayout")
        spacerItem1 = QtWidgets.QSpacerItem(10, 20, QtWidgets.QSizePolicy.Expanding, QtWidgets.QSizePolicy.Minimum)
        self.gridLayout.addItem(spacerItem1, 1, 0, 1, 1)
        self.horizontalLayout_7 = QtWidgets.QHBoxLayout()
        self.horizontalLayout_7.setSpacing(10)
        self.horizontalLayout_7.setObjectName("horizontalLayout_7")
        self.label_10 = QtWidgets.QLabel(self.centralwidget)
        sizePolicy = QtWidgets.QSizePolicy(QtWidgets.QSizePolicy.Maximum, QtWidgets.QSizePolicy.Preferred)
        sizePolicy.setHorizontalStretch(0)
        sizePolicy.setVerticalStretch(0)
        sizePolicy.setHeightForWidth(self.label_10.sizePolicy().hasHeightForWidth())
        self.label_10.setSizePolicy(sizePolicy)
        self.label_10.setAlignment(QtCore.Qt.AlignLeading|QtCore.Qt.AlignLeft|QtCore.Qt.AlignVCenter)
        self.label_10.setObjectName("label_10")
        self.horizontalLayout_7.addWidget(self.label_10, 0, QtCore.Qt.AlignRight)
        self.SpinBoxAddress = QtWidgets.QSpinBox(self.centralwidget)
        sizePolicy = QtWidgets.QSizePolicy(QtWidgets.QSizePolicy.Fixed, QtWidgets.QSizePolicy.Fixed)
        sizePolicy.setHorizontalStretch(0)
        sizePolicy.setVerticalStretch(0)
        sizePolicy.setHeightForWidth(self.SpinBoxAddress.sizePolicy().hasHeightForWidth())
        self.SpinBoxAddress.setSizePolicy(sizePolicy)
        self.SpinBoxAddress.setMinimumSize(QtCore.QSize(90, 27))
        self.SpinBoxAddress.setInputMethodHints(QtCore.Qt.ImhDigitsOnly|QtCore.Qt.ImhPreferUppercase)
        self.SpinBoxAddress.setMinimum(96)
        self.SpinBoxAddress.setMaximum(103)
        self.SpinBoxAddress.setProperty("value", 96)
        self.SpinBoxAddress.setDisplayIntegerBase(16)
        self.SpinBoxAddress.setObjectName("SpinBoxAddress")
        self.horizontalLayout_7.addWidget(self.SpinBoxAddress)
        self.gridLayout.addLayout(self.horizontalLayout_7, 1, 1, 1, 1)
        self.horizontalLayout_8 = QtWidgets.QHBoxLayout()
        self.horizontalLayout_8.setSizeConstraint(QtWidgets.QLayout.SetMinimumSize)
        self.horizontalLayout_8.setObjectName("horizontalLayout_8")
        self.label_5 = QtWidgets.QLabel(self.centralwidget)
        sizePolicy = QtWidgets.QSizePolicy(QtWidgets.QSizePolicy.Maximum, QtWidgets.QSizePolicy.Fixed)
        sizePolicy.setHorizontalStretch(0)
        sizePolicy.setVerticalStretch(0)
        sizePolicy.setHeightForWidth(self.label_5.sizePolicy().hasHeightForWidth())
        self.label_5.setSizePolicy(sizePolicy)
        self.label_5.setObjectName("label_5")
        self.horizontalLayout_8.addWidget(self.label_5)
        self.ComboBoxBus = ComboBox(self.centralwidget)
        sizePolicy = QtWidgets.QSizePolicy(QtWidgets.QSizePolicy.Fixed, QtWidgets.QSizePolicy.Fixed)
        sizePolicy.setHorizontalStretch(0)
        sizePolicy.setVerticalStretch(0)
        sizePolicy.setHeightForWidth(self.ComboBoxBus.sizePolicy().hasHeightForWidth())
        self.ComboBoxBus.setSizePolicy(sizePolicy)
        self.ComboBoxBus.setMinimumSize(QtCore.QSize(120, 0))
        self.ComboBoxBus.setEditable(False)
        self.ComboBoxBus.setCurrentText("")
        self.ComboBoxBus.setObjectName("ComboBoxBus")
        self.horizontalLayout_8.addWidget(self.ComboBoxBus)
        self.gridLayout.addLayout(self.horizontalLayout_8, 1, 3, 1, 1)
        self.horizontalLayout_6 = QtWidgets.QHBoxLayout()
        self.horizontalLayout_6.setSpacing(10)
        self.horizontalLayout_6.setObjectName("horizontalLayout_6")
        self.label_9 = QtWidgets.QLabel(self.centralwidget)
        sizePolicy = QtWidgets.QSizePolicy(QtWidgets.QSizePolicy.Maximum, QtWidgets.QSizePolicy.Preferred)
        sizePolicy.setHorizontalStretch(0)
        sizePolicy.setVerticalStretch(0)
        sizePolicy.setHeightForWidth(self.label_9.sizePolicy().hasHeightForWidth())
        self.label_9.setSizePolicy(sizePolicy)
        self.label_9.setAlignment(QtCore.Qt.AlignLeading|QtCore.Qt.AlignLeft|QtCore.Qt.AlignVCenter)
        self.label_9.setObjectName("label_9")
        self.horizontalLayout_6.addWidget(self.label_9, 0, QtCore.Qt.AlignRight)
        self.SpinBoxVdd = QtWidgets.QDoubleSpinBox(self.centralwidget)
        sizePolicy = QtWidgets.QSizePolicy(QtWidgets.QSizePolicy.Fixed, QtWidgets.QSizePolicy.Fixed)
        sizePolicy.setHorizontalStretch(0)
        sizePolicy.setVerticalStretch(0)
        sizePolicy.setHeightForWidth(self.SpinBoxVdd.sizePolicy().hasHeightForWidth())
        self.SpinBoxVdd.setSizePolicy(sizePolicy)
        self.SpinBoxVdd.setMinimumSize(QtCore.QSize(90, 27))
        self.SpinBoxVdd.setDecimals(3)
        self.SpinBoxVdd.setMinimum(2.7)
        self.SpinBoxVdd.setMaximum(5.5)
        self.SpinBoxVdd.setObjectName("SpinBoxVdd")
        self.horizontalLayout_6.addWidget(self.SpinBoxVdd)
        self.gridLayout.addLayout(self.horizontalLayout_6, 0, 1, 1, 1)
        self.horizontalLayout_9 = QtWidgets.QHBoxLayout()
        self.horizontalLayout_9.setObjectName("horizontalLayout_9")
        spacerItem2 = QtWidgets.QSpacerItem(10, 20, QtWidgets.QSizePolicy.Maximum, QtWidgets.QSizePolicy.Minimum)
        self.horizontalLayout_9.addItem(spacerItem2)
        self.CheckBoxUpdate = QtWidgets.QCheckBox(self.centralwidget)
        sizePolicy = QtWidgets.QSizePolicy(QtWidgets.QSizePolicy.Fixed, QtWidgets.QSizePolicy.Fixed)
        sizePolicy.setHorizontalStretch(0)
        sizePolicy.setVerticalStretch(0)
        sizePolicy.setHeightForWidth(self.CheckBoxUpdate.sizePolicy().hasHeightForWidth())
        self.CheckBoxUpdate.setSizePolicy(sizePolicy)
        self.CheckBoxUpdate.setMinimumSize(QtCore.QSize(170, 0))
        self.CheckBoxUpdate.setObjectName("CheckBoxUpdate")
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

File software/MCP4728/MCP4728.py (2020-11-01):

"""
MCP4728 Python Library
Copyright (C) 2019 Luca Anastasio
<anastasio.lu@gmail.com>

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
from smbus2 import SMBus, i2c_msg
from enum import Enum


class MCP4728:
	class Cmd(Enum):
		FAST_WR = 0x00
		MULT_WR = 0x40
		SING_WR = 0x58
		SEQ_WR = 0x50
		SEL_VREF = 0x80
		SEL_GAIN = 0xC0
		SEL_PWR = 0xA0
		GEN_RST = 0x06
		GEN_WAKE = 0x09
		GEN_UPD = 0x08
		GEN_ADDR = 0x0C

	from .MCP4728DAC import DAC

	# first element = select bit value, second = binary value of the bit in position
	BIT = 0
	VAL = 1

	DEV_CODE = 0x60  # or base address
	RDY_BIT = 0x80
	POR_BIT = 0x40
	ADDR_BITS = 0x07
	# this bit is set to 1 when reading from EEPROM or 0 when reading from registers
	EEPROM_READ_BIT = 0x08

	def __init__(self, bus=None, address=DEV_CODE, addrBits=0x00, update=None):
		self.address = address | addrBits
		if isinstance(bus, str):
			bus = None if len(bus) == 0 else bus
		self.i2c = SMBus(bus)
		self.channel = self.DAC(parentDac=self)
		self.EEPROMready = None
		self.VddGood = None
		self.update = update

	def SetBus(self, bus):
		if self.i2c.fd is not None:
			self.i2c.close()
		self.i2c.open(bus)

	def SetAddressBits(self, addrBits):
		self.address = self.DEV_CODE | addrBits

	def FastWrite(self, update=None):
		"""
		Writes all 4 channels' input data and power down registers (EEPROM not affected)
		NOTE: Doesn't update Vout (output data registers), use LDAC pin or GeneralCallSoftwareUpdate()
		:param update: force (enable or disable) writing registers, defaults to self.update if None
		:type update: bool
		"""
		if self.trigger(update):
			data = []
			for channel in self.channel:
				data.extend(channel.EncodeFast())
			msg = i2c_msg.write(self.address, data)
			self.i2c.i2c_rdwr(msg)

	def MultiWrite(self, channelList, update=None):
		"""
		Writes the selected channel(s) register(s) (EEPROM not affected)
		(including: data input register, gain, power down, Vref)
		Also determines if Vout gets updated or not
		:param channelList: the channel(s) to write (e.g. 'AB...' or (0,1,...))
		:type channelList: str or list of int
		:param update: trigger an update of Vout if True, else just write register, defaults to self.update
		:type update: bool
		"""
		trig = self.triggerBit(update)
		data = []
		for c in channelList:
			channel = self.channel[c]
			data.append(self.Cmd.MULT_WR.value | (channel.channelSel << 1) | trig)
			data.extend(channel.Encode())
		msg = i2c_msg.write(self.address, data)
		self.i2c.i2c_rdwr(msg)

	def SequentialWrite(self, start='A', update=None):
		"""
		Writes registers and EEPROM starting from the given channel to channel D
		:param start: the starting channel (e.g. 'A' (default) or B,C,D; 0 or 1,2,3 etc...)
		:type start: str or int
		:param update: trigger an update of Vout if True, else just write registers and EEPROM
		:type update: bool
		"""
		trig = self.triggerBit(update)
		start = int(ord(start) - ord('A')) if isinstance(start, str) else start
		data = [(self.Cmd.SEQ_WR.value | self.channel[start].channelSel << 1 | trig)]
		for c in range(start, 4):
			data.extend(self.channel[c].Encode())
		msg = i2c_msg.write(self.address, data)
		self.i2c.i2c_rdwr(msg)

	def SingleWrite(self, channel, update=None):
		"""
		Writes registers and EEPROM only for the given channel
		:param channel: channel to write (e.g. 'A' or 'B' or 'C' or 'D')
		:type channel: str
		:param update: trigger an update of Vout if True, else just write registers and EEPROM
		:type update: bool
		"""
		trig = self.triggerBit(update)
		channel = self.channel[channel]
		data = [(self.Cmd.SING_WR.value | channel.channelSel << 1 | trig), channel.Encode()]
		msg = i2c_msg.write(self.address, data)
		self.i2c.i2c_rdwr(msg)

	def WriteAddressBits(self, newaddr):
		"""
		Unimplemented, requires dedicated pin
		"""
		pass

	def WriteVref(self, update=None):
		"""
		Writes Vref selection bits, does not affect EEPROM
		:param update: force (enable or disable) an update, defaults to self.update if None
		:type update: bool
		"""
		if self.trigger(update):
			data = self.Cmd.SEL_VREF.value >> 4
			for channel in self.channel:
				data <<= 1
				data |= channel.vrefSel
			self.i2c.write_byte(self.address, data)

	def WriteGain(self, update=None):
		"""
		Writes Gain selection bits, does not affect EEPROM
		:param update: force (enable or disable) an update, defaults to self.update if None
		:type update: bool
		"""
		if self.trigger(update):
			data = self.Cmd.SEL_GAIN.value >> 4
			for channel in self.channel:
				data <<= 1
				data |= channel.gainSel
			self.i2c.write_byte(self.address, data)

	def WritePower(self, update=None):
		"""
		Writes Power selection bits, does not affect EEPROM
		:param update: force (enable or disable) an update, defaults to self.update if None
		:type update: bool
		"""
		if self.trigger(update):
			data = self.Cmd.SEL_PWR.value >> 4
			for channel in self.channel:
				data <<= 2
				data |= channel.powerSel
			data <<= 4
			msg = i2c_msg.write(self.address, list(data.to_bytes(2, 'big')))
			self.i2c.i2c_rdwr(msg)

	def ReadAll(self, restore=None):
		"""
		Reads registers or EEPROM contents and optionally saves values in current instance
		:param restore: which contents to restore, either None (default), 'R' or 0 for registers and 'E' or 1 for EEPROM
		:type restore: str
		:return: list of DAC objects [registers, EEPROM]
		"""
		msg = i2c_msg.read(self.address, 24)
		self.i2c.i2c_rdwr(msg)
		msg = bytes(msg)
		self.ReadStatus(msg[0])
		reg = self.DAC()
		eep = self.DAC()

		for i in range(0, 24, 3):
			channel = self.DAC.Channel(parentDac=self)
			channel.Decode(msg[i:i + 3])
			if bool(msg[i] & self.EEPROM_READ_BIT) is True:
				eep[channel.channelSel] = channel
			else:
				reg[channel.channelSel] = channel

		if restore == 'R' or 0:
			self.channel = reg
		elif restore == 'E' or 1:
			self.channel = eep
		return [reg, eep]

	def ReadStatus(self, sByte=None):
		"""
		Quickly reads status bits only and saves values in the current instance
		(updates EEPROMready and VddGood fields)
		:param sByte: optional (default None) for internal reading
		:type sByte: byte
		"""
		if sByte is None:
			sByte = self.i2c.read_byte(self.address)
		self.EEPROMready = bool(sByte & MCP4728.RDY_BIT)
		self.VddGood = bool(sByte & MCP4728.POR_BIT)

	@staticmethod
	def DecodeStatus(statusByte):
		return {'RDY': bool(statusByte & MCP4728.RDY_BIT),
				'POR': bool(statusByte & MCP4728.POR_BIT),
				'addrBits': statusByte & MCP4728.ADDR_BITS}


	def GeneralCallReset(self):
		"""
		Resets devices on bus, devices load EEPROM values afeter reset
		"""
		#self.i2c.write_byte(i2c_addr=0x00, value=self.Cmd.GEN_RST.value)
		pass

	def GeneralCallWakeUp(self):
		"""
		Resets power down bits for all channels to 00
		"""
		#self.i2c.write_byte(i2c_addr=0x00, value=self.Cmd.GEN_WAKE.value)
		pass

	def GeneralCallSoftwareUpdate(self):
		"""
		Updates all channels' outputs simultaneously
		"""
		#self.i2c.write_byte(i2c_addr=0x00, value=self.Cmd.GEN_UPD.value)
		pass
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

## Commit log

2019-12-16 board + modified AWR
    [Filter_PCB.kicad_pcb, Filter_PCB.sch]
2019-12-16 KiCad gitignore
2019-12-16 footprint replacement
    [Filter_PCB.kicad_pcb, Filter_PCB.sch]
2019-12-17 modifche AWR + PCB
    [Filter_PCB_2.kicad_pcb, Filter_PCB_2.sch, Filter_PCB_4.kicad_pcb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]
2019-12-23 varactor version added in tunable filter file
2019-12-27 aggiunti condensatori di disaccoppiamento
    Non c'è nessuna variazione della risposta in frequenza, i condensatori di disaccoppiamento sono di 10 nano
2019-12-27 file di tognolatti + funzione per tensione varactor nel file tunable filter
2019-12-27 new ideal reference filter
2019-12-28 jig varactor added
    [Jig_Varactor.kicad_pcb, Jig_Varactor.sch]
2019-12-28 varactor test jig
    [Jig_Varactor.kicad_pcb, Jig_Varactor.sch]
2019-12-29 Aggiunto schematico con induttori reali
2019-12-30 README.tex aggiornato.
    Inserito screenshoot di AWR come immagine. In seguito la sostituirò con uno schematico fatt meglio.
2020-01-02 Aggiunto modello SPICE varactor + setup di misura
    Ho aggiunto una cartella con il modello spice del varactor implementato come subcircuit. La validità di tale modello è stata testata con la curva C vs V del varactor SMV1235 della skyworks. Inoltre n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
2020-01-02 Aggiornato il file tunable_filter
    Aggiunta la versione con varactor BB202 e anche la netlist del BB181. Bisogna ricontrollare la funzone ricavata per il BB202.
2020-01-03 filter with BB202 model
2020-01-07 Filter with SMV1705 and readme
    -Aggiunto schematico filtro tunabile con varactor SMV1705
    -Aggiornato README con risposta in frequenza (solo S21)
2020-01-08 RF layout
    [Filter_PCB_4.kicad_pcb, Filter_PCB_4.sch, I2C.sch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]
2020-01-08 filter corrections
    [Filter_PCB_4.kicad_pcb]
2020-01-08 PCB layout
    [Filter_PCB_4.kicad_pcb, inverter.sch, logic.sch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]
2020-01-09 Lp compensation
    [Filter_PCB_4-B_Cu.gbr, Filter_PCB_4-B_Mask.gbr, Filter_PCB_4-B_Paste.gbr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]
2020-01-10 Create Tunable_filter_final.emp
    - aggiunti varactor parallelo per versione con SMV1705
    - tutti i circuiti nel file sono a componenti reali
    - aggiunta configurazione back to back per ridurre le capacità dei varactor serie
2020-01-14 btob pcb
    [DAC.sch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]
2020-01-14 PCB updated
    resistori 0603 sostituiti da resistori 0402
    [Filter_PCB_4_btob.kicad_pcb, RF.sch, inverter.sch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]
2020-02-04 gui i2c adapter
2020-02-04 pcb4 board update
    [Filter_PCB_4_btob.kicad_pcb]
2020-02-19 filter gui

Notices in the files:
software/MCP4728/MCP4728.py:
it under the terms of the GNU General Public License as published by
